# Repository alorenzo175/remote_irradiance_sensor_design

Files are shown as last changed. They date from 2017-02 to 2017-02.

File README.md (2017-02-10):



# Remote Irradiance Sensors

This repositories contains the circuit board design for sensors that are
deployed remotely, communicate in real-time via a cellular data network,
and are power by a solar panel. The sensors were designed to specifically
measure irradiance to support short term forecasting [1,2].

[1] A. T. Lorenzo, W. F. Holmgren, and A. D. Cronin, “Irradiance forecasts based
    on an irradiance monitoring network , cloud motion , and spatial averaging,”
    Sol. Energy, vol. 122, pp. 1158–1169, 2015.

[2] A. T. Lorenzo, M. Morzfeld, W. F. Holmgren, and A. D. Cronin,
    “Optimal interpolation of satellite and ground data for irradiance
    nowcasting at city scales,” Sol. Energy, vol. 144, pp. 466–474, 2017.

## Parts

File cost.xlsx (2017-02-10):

Id | Designator | Package | Quantity | Designation | Supplier and ref | Unit Price | Total Price
1 | U7 | Olinuxino_i.MX223 | 1 | Olinuxino imx223 micro | Mouser | $29.95 | $29.95
2 | U2 | TO92 | 1 | LM61 | Mouser | $0.86 | $0.86
3 | U4 | TO92 | 1 | MCP1541 | Mouser | $0.92 | $0.92
4 | U8 | MTSMC | 1 | MTSMC-H5 | Digikey | $198.17 | $198.17
5 | C5 | C1V7 | 1 | 68 uF | Mouser | $0.34 | $0.34
6 | P3 | PINHEAD1-2 | 1 | CONN_2 | Mouser | $0.41 | $0.41
7 | C1,C2 | C1 | 2 | 4.7 uF | Mouser | $0.48 | $0.96
8 | C3 | C2 | 1 | 100 nF | Mouser | $0.10 | $0.10
9 | C4 | C1 | 1 | 10 nF | Mouser | $0.10 | $0.10
10 | C6,C8,C9,C10,C11 | C1 | 5 | 1uF | Mouser | $0.24 | $1.20
11 | C7 | C1 | 1 | 330pF | Mouser | $0.19 | $0.19
12 | C12 | C2 | 1 | 0.1uF | Mouser | $0.10 | $0.10
13 | C13 | C1 | 1 | 10uF | Mouser | $0.40 | $0.40
14 | D1 | D4 | 1 | SR305 | Mouser | $0.25 | $0.25
15 | L1 | L15-E | 1 | 100 uH | Mouser | $3.27 | $3.27
16 | P1,P2 | SIL-2 | 2 | CONN_2 |  |  | $0.00
17 | R1 | R1 | 1 | 50k | Mouser | $0.34 | $0.34
18 | R2 | R1 | 1 | 20k | Mouser | $0.34 | $0.34
19 | R4 | R1 | 1 | 680 | Mouser | $0.82 | $0.82
20 | U1 | TO220-7 | 1 | LM2676 | Mouser | $4.05 | $4.05
21 | U3 | DIP-8__300 | 1 | MCP602 | Mouser | $0.62 | $0.62
22 | U6 | DIP-14__300 | 1 | MCP3204 | Mouser | $3.34 | $3.34
23 | J1 | USB_B | 1 | USB | Mouser | $0.75 | $0.75
24 | U5 | DIP-8__300 | 1 | MCP3201 | Mouser | $2.40 | $2.40
25 | K1 | KLDX-0202-A-LT | 1 | CONN_3 | Mouser | $0.80 | $0.80
26 | P4,P5,P6,P7 | 1pin | 4 | CONN_1 |  |  | $0.00
 |  | Air/moisture vent | 1 | NBX-10910 | Mouser | $3.00 | $3.00
 |  | Standoffs 1" | 4 |  | Mouser | $0.72 | $2.88
 |  | standoffs 7mm | 3 |  | Mouser | $0.35 | $1.05
 |  | 3 pin header | 1 |  | Mouser | $1.15 | $1.15
 |  | 5 pin header | 1 |  | Mouser | $1.52 | $1.52
 |  | 9 pin header | 1 |  | Mouser | $1.77 | $1.77
 |  | 14 pin socket | 1 |  |  | $0.36 | $0.36
 |  | 8 pin socket | 2 |  |  | $0.19 | $0.38
 |  | 30 pin header | 2 |  |  | $1.65 | $3.30
 |  | Box | 1 | carlon 8x8x4 junction box | Home Depot | $22.64 | $22.64
 |  | Solar panel | 1 | Aleko 10 W | Amazon | $39.99 | $39.99
 |  | Charge Controller | 1 | Sungard sg-4 | Amazon | $33.00 | $33.00
 |  | Battery | 1 | ps-1270 12 v 7 ah | Battery Systems | $19.11 | $19.11
 |  | USB a-b cable | 1 |  | Mouser | $2.94 | $2.94
 |  | PCB | 1 |  | 4pcb | $16.97 | $16.97
 |  | cell antenna | 1 |  | Mouser | $6.74 | $6.74
 |  | 8 GB sd card | 1 | SDSDQ-008G-AFFP | Amazon | $7.95 | $7.95
 |  | Cable glands | 2 |  | Mouser | $1.80 | $3.60
 |  | Misc screws etc | 1 |  |  | $5.00 | $5.00
 |  | photodiode | 1 | PD333 | Mouser | $0.76 | $0.76
 |  | Sensor enclosure | 1 | CU-1941 | Mouser | $2.10 | $2.10
 |  | LED mount | 1 |  | Mouser | $0.15 | $0.15
 | Mouser project | http://www.mouser.com/ProjectManager/ProjectDetail.aspx?AccessID=86f0dea51c

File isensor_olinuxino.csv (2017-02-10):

Id | Designator | Package | Quantity | Designation | Supplier and ref
1 | U7 | Olinuxino_i.MX223 | 1 | OLINXUINO_I.MX223
2 | U2 | TO92 | 1 | LM61
3 | U4 | TO92 | 1 | MCP1541
4 | U8 | MTSMC | 1 | MTSMC
5 | C5 | C1V7 | 1 | 68 uF
6 | P3 | PINHEAD1-2 | 1 | CONN_2
7 | C1,C2 | C1 | 2 | 4.7 uF
8 | C3 | C2 | 1 | 100 nF
9 | C4 | C1 | 1 | 10 nF
10 | C6,C8,C9,C10,C11 | C1 | 5 | 1uF
11 | C7 | C1 | 1 | 330pF
12 | C12 | C2 | 1 | 0.1uF
13 | C13 | C1 | 1 | 10uF
14 | D1 | D4 | 1 | SR305
15 | L1 | L15-E | 1 | 100 uH
16 | P1,P2 | SIL-2 | 2 | CONN_2
17 | R1 | R1 | 1 | 50k
18 | R2 | R1 | 1 | 20k
19 | R4 | R1 | 1 | 680
20 | U1 | TO220-7 | 1 | LM2676
21 | U3 | DIP-8__300 | 1 | MCP602
22 | U6 | DIP-14__300 | 1 | MCP3204
23 | J1 | USB_B | 1 | USB
24 | U5 | DIP-8__300 | 1 | MCP3201
25 | K1 | KLDX-0202-A-LT | 1 | CONN_3
26 | P4,P5,P6,P7 | 1pin | 4 | CONN_1

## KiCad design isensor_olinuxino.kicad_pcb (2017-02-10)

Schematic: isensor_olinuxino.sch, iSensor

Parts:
C1, C2: 4.7 uF; C1
C3: 100 nF; C2
C4: 10 nF; C1
C5: 68 uF; C1V7
C6, C8, C9, C10, C11: 1uF; C1
C7: 330pF; C1
C12: 0.1uF; C2
C13: 10uF; C1
D1: SR305; D4
J1: USB; USB_B
K1: CONN_3; BARREL_JACK
L1: 100 uH; L15-E
P1, P2: CONN_2; SIL-2
P3: CONN_2; PINHEAD1-2
P4, P5, P6, P7: CONN_1
R1: 50k; R1
R2: 20k; R1
R4: 680; R1
U1: LM2676; TO220-7
U2: LM61
U3: MCP602; DIP-8__300
U4: MCP1541; TO92
U5: MCP3201; DIP-8__300
U6: MCP3204; DIP-14__300
U7: OLINXUINO_I.MX223; Olinuxino_i.MX223
U8: MTSMC

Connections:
+5V: C5.1, C6.1, C10.1, C11.1, C12.1, C13.1, L1.2, U1.6 (Fdback), U2.1 (+Vs), U3.8 (VDD), U4.3 (VIN), U5.8 (VDD), U6.14 (VDD), U7.1, U7.31, U8.61 (VCC)
+12V: C1.1, C2.1, C3.1, K1.1, R1.1, U1.2 (In)
/SIG1: U5.7 (CLK), U7.3
/SIG2: U5.6 (DOUT), U7.4
/SIG3: U5.5 (~CS~/SHDN), U7.5
/SIG4: U6.11 (CLK), U7.6
/SIG5: U6.10 (DOUT), U7.7
/SIG6: U6.9 (DIN), U7.8
/SIG7: U6.8 (~CS~/SHDN), U7.9
GND: C1.2, C2.2, C3.2, C5.2, C6.2, C8.1, C9.2, C10.2, C11.2, C12.2, C13.2, D1.1 (A), J1.4 (GND), J1.5 (Shield_1), J1.6 (Shield_2), K1.2 (PM), K1.3, P1.2 (PM), P2.2 (PM), P3.2 (PM), R2.2, U1.4 (GND), U2.3 (GND), U3.3 (VINA+), U3.4 (VSS), U4.1 (VSS), U5.3 (IN-), U5.4 (VSS), U6.7 (DGND), U6.12 (AGND), U7.2, U7.29, U7.32, U7.34, U7.59, U8.26 (GND_2), U8.33 (RTS), U8.40 (DTR), U8.41 (GND_1), U8.63 (GND)
unnamed: C8.2, C9.1, U4.2 (VOUT), U5.1 (VREF), U6.13 (VREF)
unnamed: C4.2, D1.2 (K), L1.1, U1.1 (Out)
unnamed: C4.1, U1.3 (Cb)
unnamed: C7.2, R4.2, U3.1 (VOUTA), U5.2 (IN+)
unnamed: J1.2 (D-), U8.28 (USB_DN)
unnamed: J1.3 (D+), U8.27 (USB_DP)
unnamed: J1.1 (Vbus), U8.25 (USB_VBUS)
unnamed: U2.2 (Vout), U6.2 (CH1)
unnamed: P2.1, U6.4 (CH3)
unnamed: P1.1, U6.3 (CH2)
unnamed: U3.6 (VINB-), U3.7 (VOUTB), U6.1 (CH0)
unnamed: R1.2, R2.1, U3.5 (VINB+)
unnamed: C7.1, P3.1, R4.1, U3.2 (VINA-)
unnamed: U7.58, U8.24 (RESET)
unnamed: U7.35, U8.35 (TXD)
unnamed: U7.36, U8.34 (RXD)

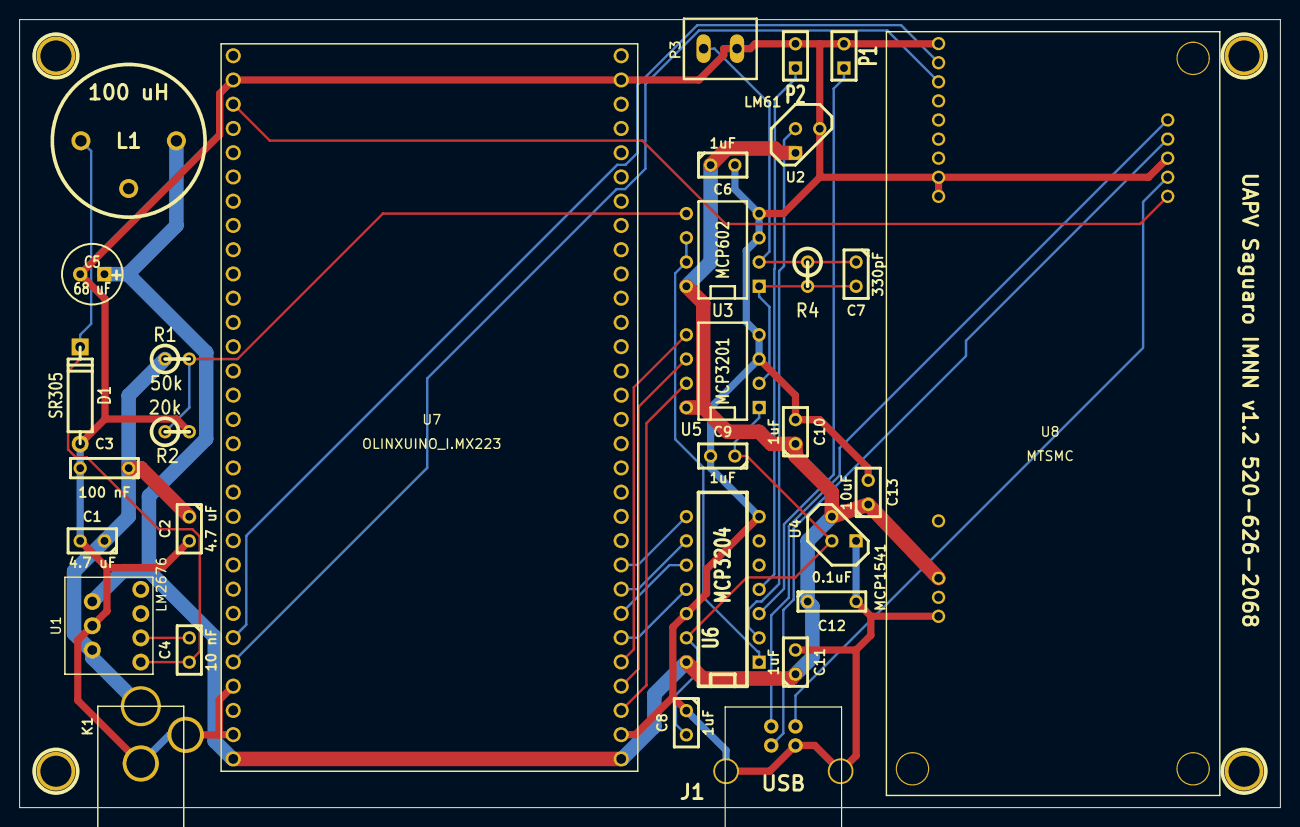
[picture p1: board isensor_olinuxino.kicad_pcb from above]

Board: 2 copper layers, 132.1 x 82.5 mm, 35 parts (0 on the bottom side), 26 nets.
